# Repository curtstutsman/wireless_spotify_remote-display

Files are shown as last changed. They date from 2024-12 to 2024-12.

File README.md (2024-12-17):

Wireless Spotify Remote Control and Display
Curt Stutsman & Nicholas Watanabe
https://github.com/curtstutsman/wireless_spotify_remote-display

Introduction
	Our group elected to implement a wireless Spotify remote control and album art display utilizing Spotify’s API to control the listening state of the user. Some features of the project include a rotary encoder (which doubled as a push button) and a 64x64 LED matrix. The rotary encoder was purposed for all input, allowing the user to adjust volume with rotations and toggle play/pause and skip to next or previous songs with single, double, and triple taps. The LED matrix was the primary output of the system, displaying in real time the album art of whatever song was currently playing. To achieve wireless communication with Spotify’s api, our group employed and ESP32-WROOM-32E wireless module. The rest of the functionality (LED driving, GPIO interface, etc.) was implemented on an STM32F103.

Figure 1: System Block Diagram

Hardware Overview
	Our project did not require an extensive list of hardware components to achieve the desired functionality. For the LED matrix, we used a 64x64 panel purchased from adafruit with a 2.5mm pitch. Each LED held a one bit value for each of red, green, and blue channels. The matrix as a whole was controlled via the HUB75 protocol, a standard for these types of LED matrices that utilized 16 different signals in the case of our matrix. The 16 signals of the HUB75 protocol were connected and controlled from the GPIO pins of the STM32. The rotary encoder was also controlled via GPIO pins on the MCU. We used a simple UART connection between the STM32 and the ESP32 to send commands to the ESP and to receive image data into the STM. A few other trivial components were included in the final PCB design such as reset buttons, headers for programming, and decoupling capacitors. The full schematic and PCB layout is given below and is linked on our github repository.

Figure 2: Schematic

Figure 3: PCB Layout

Software Overview
	Because we utilized two different chips in our project, the software was split between the STM32F103, which handled LED driving and input control, and the ESP32, which handled communication with the Spotify API and JPEG Decoding. All code can be found in the main.c file of the STM32 source code and the esp32_sketch.ino file of the ESP32 source code, both available on the github repo.

	The first functionality implemented was the button control. The rotary encoder consists of three signals, two for rotation encoding and one for the button. All three channels were connected to GPIO pins and configured to interrupt the CPU at the rising edge of the signal. Pushes to the button increase the tap count variable. The main loop would then check if tap count was greater than zero and enough time had passed since the last tap (to account for double and triple taps) and then send the corresponding command over UART to the ESP32. Interrupts for rotation of the encoder worked in a similar fashion, except a comparison had to be done between the two rotation signals to determine if the rotation was clockwise or counter clockwise so we could tell whether to send the increase or decrease volume command. The LED driving code is by far the most complicated of all the software we wrote. The first task was understanding and implementing the HUB75 protocol, which involved the control of 6 different color signals, 5 addressing signals, and 3 control signals all operating in unison to even turn on the display. Another challenge stemmed from the fact that each LED actually only held one bit for red, green, and blue each, meaning if we wanted to display a color that wasn’t a direct combination of these three, we had to implement a PWM control over the LEDs. For example, to display a red color with 50% intensity, we would have to turn on the red color for that pixel for 50% of the cycles. We were able to adequately control this by looping through the range of the bit magnitude of our colors and adjusting the delay the pixel was on for by this magnitude, giving the appearance of different colors. This however, required extremely fast speeds in order to avoid flickering in the display. The actual pixel data was received directly from ESP32 into an image buffer, which was used to draw from.

	In comparison the code for the ESP32 was simpler apart from a few small details. All of the ESP32 development was done in the Arduino IDE, which made programming the chip much easier. Many of the functions were simple HTTP requests based on their respective commands from the rotary encoder input. The ESP32 was constantly listening for these commands over the serial line it shared with the STM32. The ESP was also constantly checking if the album link had changed, meaning a new song was playing and new image data needed to be sent to the STM32. If there was a new song, it was downloaded from the link (which is provided by the Spotify API), saved to SPIFFS (the ESP32’s built in filesystem), decoded into the raw pixel values, formatted to fit our 8 bits of color standard (RGB332) and sent over UART to the STM32 for storage in its image buffer. There are a few authorization requirements as well as set up steps in the Spotify Developer Dashboard to grant permissions to our project to view and control a selected spotify account, but these are not included in our source code and can be deduced from Spotify’s Web API Documentation. 

Design Challenges and Solutions:
An initial challenge we ran into was the wifi module. To begin we first used the ESP8266 which had less capabilities (and was much harder to use than the ESP32). We were originally trying to rely on the AT command set from Espressif to control the chip, however both the ESP8266 and the AT Firmware were unable to connect to the WPA2-Enterprise level security deployed by the IllinoisNet wifi network. Also, employing only AT commands would not give us enough control over the wireless chip. As a solution, we switched to the more powerful ESP32 and the Arduino IDE, which allowed us to upload code straight to the chip as well as utilize some helpful WiFi libraries.

Another large issue we faced was the refresh rate of the LED matrix. Matrices controlled by the HUB75 protocol only actually turn on two rows of LEDs at a time, and only while the Output Enable signal is high. The rows are cycled on and on so fast that to the human eye it appears to be a fully lit screen. However, if the driver is not updating the rows fast enough, major flickering will occur on the screen. Furthermore, implementing PWM and more than 3 bits of color meant even more cycles until an entire image was properly displayed (and more memory to store the image buffer). To overcome this, we elected to use a larger and faster MCU than the standard STM32L0 given to us. We also spent a lot of time optimizing our main display loop, trying to avoid calculations within the loop wherever possible and instead relying on lookup-tables defined on startup for proper calculations. We also had to bypass the HAL interface for writing to the GPIO pins, and instead wrote directly to the GPIO registers on the chip. 

 When we implemented the PCB board we ran into the issue uploading code. The new STM we used for the PCB (STM32F103) needs to have the reset pin connected to the programmer when uploading code. To solve this we soldered a wire to both pins on the PCB. Furthermore, we had to create two different voltage sources as our rotary encoder required 5V to operate while the rest of the components like the microcontroller and wifi module required 3.3V.

Project Replication

If one wishes to replicate this project in its entirety, the steps taken are as follows:

1. Download the gbr files from github repo, and send them to your favorite pcb manufacturer (you may want to make the wiring changes mentioned in the third paragraph of section IV).
2. Purchase the parts listed in FinalPCBBoard1/FinalPCBBoard1.xml in the repo
3. Solder all of the components to the board
4. Program the ESP32 using the Arduino IDE and the provided sketch + libraries
5. Create a new STM32 project selecting the F103 as the part and add all of the files from the github repo (be sure the pinouts are the same as the final.ioc file)
6. Program the STM32 and ESP32 on your PCB
7. Supply 3.3V directly to the LDO output pins
8. Apply a 5V souce to the power source on the rotary encoder

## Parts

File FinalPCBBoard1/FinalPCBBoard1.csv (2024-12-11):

Source: | C:\Users\ntw5\Documents\FinalPCBBoard1\FinalPCBBoard1.kicad_sch
Date: | 11/19/2024 4:20:24 PM
Tool: | Eeschema (6.0.5)
Generator: | C:\Program Files\KiCad\6.0\bin\scripting\plugins/bom_csv_grouped_by_value.py
Component Count: | 27
Individual Components:
Item | Qty | Reference(s) | Value | LibPart | Footprint | Datasheet
 |  | C1 | 1u | Device:C | Capacitor_SMD:C_0805_2012Metric_Pad1.18x1.45mm_HandSolder | ~
 |  | C4 | 1u | Device:C | Capacitor_SMD:C_0805_2012Metric_Pad1.18x1.45mm_HandSolder | ~
 |  | C7 | 1u | Device:C | Capacitor_SMD:C_0805_2012Metric_Pad1.18x1.45mm_HandSolder | ~
 |  | C10 | 1u | Device:C | Capacitor_SMD:C_0805_2012Metric_Pad1.18x1.45mm_HandSolder | ~
 |  | C11 | 1u | Device:C | Capacitor_SMD:C_0805_2012Metric_Pad1.18x1.45mm_HandSolder | ~
 |  | C12 | 1u | Device:C | Capacitor_SMD:C_0805_2012Metric_Pad1.18x1.45mm_HandSolder | ~
 |  | C13 | 1u | Device:C | Capacitor_SMD:C_0805_2012Metric_Pad1.18x1.45mm_HandSolder | ~
 |  | C14 | 1u | Device:C | Capacitor_SMD:C_0805_2012Metric_Pad1.18x1.45mm_HandSolder | ~
 |  | C15 | 1u | Device:C | Capacitor_SMD:C_0805_2012Metric_Pad1.18x1.45mm_HandSolder | ~
 |  | ESPBOOT1 | SW_Push | Switch:SW_Push | Button_Switch_THT:SW_PUSH_6mm_H4.3mm | ~
 |  | ESPEN1 | SW_Push | Switch:SW_Push | Button_Switch_THT:SW_PUSH_6mm_H4.3mm | ~
 |  | ESPPROGRAM1 | Conn_01x06 | Connector_Generic:Conn_01x06 | Connector_PinSocket_2.54mm:PinSocket_1x06_P2.54mm_Horizontal | ~
 |  | FB1 | FerriteBead | Device:FerriteBead | Ferrite_THT:LairdTech_28C0236-0JW-10 | ~
 |  | J1 | USB_C_Receptacle_USB2.0 | Connector:USB_C_Receptacle_USB2.0 | Connector_USB:USB_C_Receptacle_GCT_USB4085 | https://www.usb.org/sites/default/files/documents/usb_type-c.zip
 |  | J2 | Conn_02x08_Odd_Even | Connector_Generic:Conn_02x08_Odd_Even | Connector_PinHeader_2.54mm:PinHeader_2x08_P2.54mm_Vertical | ~
 |  | J3 | Conn_01x05 | Connector_Generic:Conn_01x05 | Connector_PinSocket_2.54mm:PinSocket_1x05_P2.54mm_Horizontal | ~
 |  | J4 | Conn_02x10_Odd_Even | Connector_Generic:Conn_02x10_Odd_Even | Connector_PinSocket_2.54mm:PinSocket_2x10_P2.54mm_Vertical | ~
 |  | R1 | 10k | Device:R | Resistor_SMD:R_0805_2012Metric_Pad1.20x1.40mm_HandSolder | ~
 |  | R2 | 10k | Device:R | Resistor_SMD:R_0805_2012Metric_Pad1.20x1.40mm_HandSolder | ~
 |  | R3 | 10k | Device:R | Resistor_SMD:R_0805_2012Metric_Pad1.20x1.40mm_HandSolder | ~
 |  | R4 | 10k | Device:R | Resistor_SMD:R_0805_2012Metric_Pad1.20x1.40mm_HandSolder | ~
 |  | STMPROGRAM1 | Conn_01x06 | Connector_Generic:Conn_01x06 | Connector_PinSocket_2.54mm:PinSocket_1x06_P2.54mm_Vertical | ~
 |  | STMRST1 | SW_Push | Switch:SW_Push | Button_Switch_THT:SW_PUSH_6mm_H4.3mm | ~
 |  | STMRST2 | SW_Push | Switch:SW_Push | Button_Switch_THT:SW_PUSH_6mm_H4.3mm | ~
 |  | U1 | ESP32-WROOM-32 | RF_Module:ESP32-WROOM-32 | RF_Module:ESP32-WROOM-32 | https://www.espressif.com/sites/default/files/documentation/esp32-wroom-32_datasheet_en.pdf
 |  | U2 | TC1262-33 | Regulator_Linear:TC1262-33 | Package_TO_SOT_SMD:SOT-223 | http://ww1.microchip.com/downloads/en/DeviceDoc/21373C.pdf
 |  | U3 | STM32F103C8T6 | MCU_ST_STM32F1:STM32F103C8Tx | Package_QFP:LQFP-48_7x7mm_P0.5mm | http://www.st.com/st-web-ui/static/active/en/resource/technical/document/datasheet/CD00161566.pdf
Collated Components:
Item | Qty | Reference(s) | Value | LibPart | Footprint | Datasheet
1 | 9 | C1, C4, C7, C10, C11, C12, C13, C14, C15 | 1u | Device:C | Capacitor_SMD:C_0805_2012Metric_Pad1.18x1.45mm_HandSolder | ~
2 | 4 | ESPBOOT1, ESPEN1, STMRST1, STMRST2 | SW_Push | Switch:SW_Push | Button_Switch_THT:SW_PUSH_6mm_H4.3mm | ~
3 | 1 | ESPPROGRAM1 | Conn_01x06 | Connector_Generic:Conn_01x06 | Connector_PinSocket_2.54mm:PinSocket_1x06_P2.54mm_Horizontal | ~
4 | 1 | FB1 | FerriteBead | Device:FerriteBead | Ferrite_THT:LairdTech_28C0236-0JW-10 | ~
5 | 1 | J1 | USB_C_Receptacle_USB2.0 | Connector:USB_C_Receptacle_USB2.0 | Connector_USB:USB_C_Receptacle_GCT_USB4085 | https://www.usb.org/sites/default/files/documents/usb_type-c.zip
6 | 1 | J2 | Conn_02x08_Odd_Even | Connector_Generic:Conn_02x08_Odd_Even | Connector_PinHeader_2.54mm:PinHeader_2x08_P2.54mm_Vertical | ~
7 | 1 | J3 | Conn_01x05 | Connector_Generic:Conn_01x05 | Connector_PinSocket_2.54mm:PinSocket_1x05_P2.54mm_Horizontal | ~
8 | 1 | J4 | Conn_02x10_Odd_Even | Connector_Generic:Conn_02x10_Odd_Even | Connector_PinSocket_2.54mm:PinSocket_2x10_P2.54mm_Vertical | ~
9 | 4 | R1, R2, R3, R4 | 10k | Device:R | Resistor_SMD:R_0805_2012Metric_Pad1.20x1.40mm_HandSolder | ~
10 | 1 | STMPROGRAM1 | Conn_01x06 | Connector_Generic:Conn_01x06 | Connector_PinSocket_2.54mm:PinSocket_1x06_P2.54mm_Vertical | ~
11 | 1 | U1 | ESP32-WROOM-32 | RF_Module:ESP32-WROOM-32 | RF_Module:ESP32-WROOM-32 | https://www.espressif.com/sites/default/files/documentation/esp32-wroom-32_datasheet_en.pdf
12 | 1 | U2 | TC1262-33 | Regulator_Linear:TC1262-33 | Package_TO_SOT_SMD:SOT-223 | http://ww1.microchip.com/downloads/en/DeviceDoc/21373C.pdf
13 | 1 | U3 | STM32F103C8T6 | MCU_ST_STM32F1:STM32F103C8Tx | Package_QFP:LQFP-48_7x7mm_P0.5mm | http://www.st.com/st-web-ui/static/active/en/resource/technical/document/datasheet/CD00161566.pdf

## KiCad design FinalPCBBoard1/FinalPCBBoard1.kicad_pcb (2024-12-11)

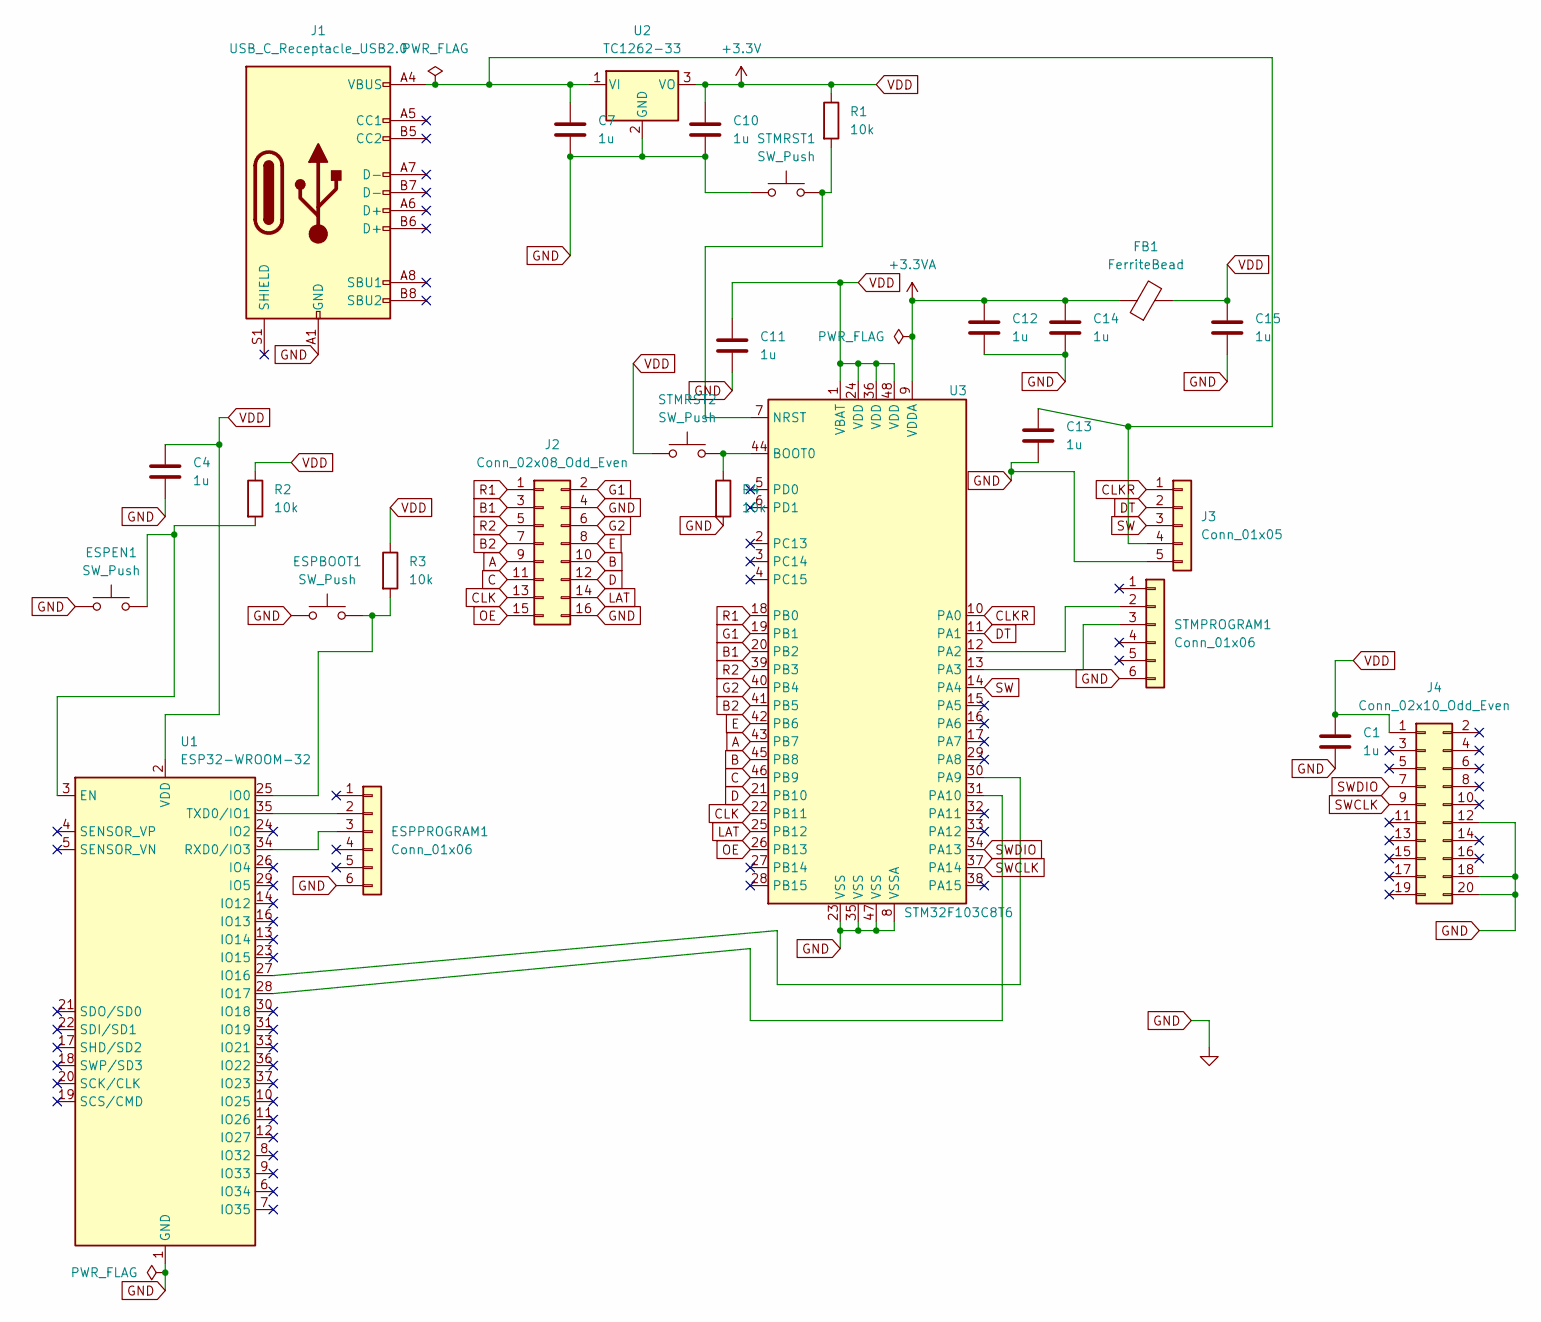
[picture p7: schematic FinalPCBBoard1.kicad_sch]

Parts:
C1, C4, C7, C10, C11, C12, C13, C14, C15: 1u; C_0805_2012Metric_Pad1.18x1.45mm_HandSolder
ESPBOOT1: SW_Push; SW_PUSH_6mm_H4.3mm
ESPEN1: SW_Push; SW_PUSH_6mm_H4.3mm
ESPPROGRAM1: Conn_01x06; PinSocket_1x06_P2.54mm_Horizontal
FB1: FerriteBead; LairdTech_28C0236-0JW-10
J1: USB_C_Receptacle_USB2.0; USB_C_Receptacle_GCT_USB4085
J2: Conn_02x08_Odd_Even; PinHeader_2x08_P2.54mm_Vertical
J3: Conn_01x05; PinSocket_1x05_P2.54mm_Horizontal
J4: Conn_02x10_Odd_Even; PinSocket_2x10_P2.54mm_Vertical
R1, R2, R3, R4: 10k; R_0805_2012Metric_Pad1.20x1.40mm_HandSolder
STMPROGRAM1: Conn_01x06; PinSocket_1x06_P2.54mm_Vertical
STMRST1, STMRST2: SW_Push; SW_PUSH_6mm_H4.3mm
U1: ESP32-WROOM-32
U2: TC1262-33; SOT-223
U3: STM32F103C8T6; LQFP-48_7x7mm_P0.5mm

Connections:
+3.3VA: C12.1, C14.1, FB1.1, U3.9 (VDDA)
A: J2.9, U3.43 (PB7)
B: J2.10, U3.45 (PB8)
B1: J2.3, U3.20 (PB2)
B2: J2.7, U3.41 (PB5)
C: J2.11, U3.46 (PB9)
CLK: J2.13, U3.22 (PB11)
CLKR: J3.1, U3.10 (PA0)
D: J2.12, U3.21 (PB10)
DT: J3.2, U3.11 (PA1)
E: J2.8, U3.42 (PB6)
G1: J2.2, U3.19 (PB1)
G2: J2.6, U3.40 (PB4)
GND: C1.2, C4.2, C7.2, C10.2, C11.2, C12.2, C13.2, C14.2, C15.2, ESPBOOT1.1, ESPEN1.1, ESPPROGRAM1.6, J1.A1 (GND), J1.A12 (GND), J1.B1 (GND), J1.B12 (GND), J2.4, J2.16, J3.5, J4.12, J4.18, J4.20, R4.2, STMPROGRAM1.6, STMRST1.1, U1.1 (GND), U1.15 (GND), U1.38 (GND), U1.39 (GND), U2.2 (GND), U3.8 (VSSA), U3.23 (VSS), U3.35 (VSS), U3.47 (VSS)
LAT: J2.14, U3.25 (PB12)
unnamed: C7.1, C13.1, J1.A4 (VBUS), J1.A9 (VBUS), J1.B4 (VBUS), J1.B9 (VBUS), J3.4, U2.1 (VI)
unnamed: ESPBOOT1.2, R3.2, U1.25 (IO0)
unnamed: ESPEN1.2, R2.2, U1.3 (EN)
unnamed: ESPPROGRAM1.2, U1.35 (TXD0/IO1)
unnamed: ESPPROGRAM1.3, U1.34 (RXD0/IO3)
unnamed: R1.2, STMRST1.2, U3.7 (NRST)
unnamed: STMPROGRAM1.2, U3.12 (PA2)
unnamed: STMPROGRAM1.3, U3.13 (PA3)
unnamed: U1.27 (IO16), U3.30 (PA9)
unnamed: U1.28 (IO17), U3.31 (PA10)
unnamed: R4.1, STMRST2.2, U3.44 (BOOT0)
OE: J2.15, U3.26 (PB13)
R1: J2.1, U3.18 (PB0)
R2: J2.5, U3.39 (PB3)
SW: J3.3, U3.14 (PA4)
SWCLK: J4.9, U3.37 (PA14)
SWDIO: J4.7, U3.34 (PA13)
VDD: C1.1, C4.1, C10.1, C11.1, C15.1, FB1.2, J4.1, R1.1, R2.1, R3.1, STMRST2.1, U1.2 (VDD), U2.3 (VO), U3.1 (VBAT), U3.24 (VDD), U3.36 (VDD), U3.48 (VDD)

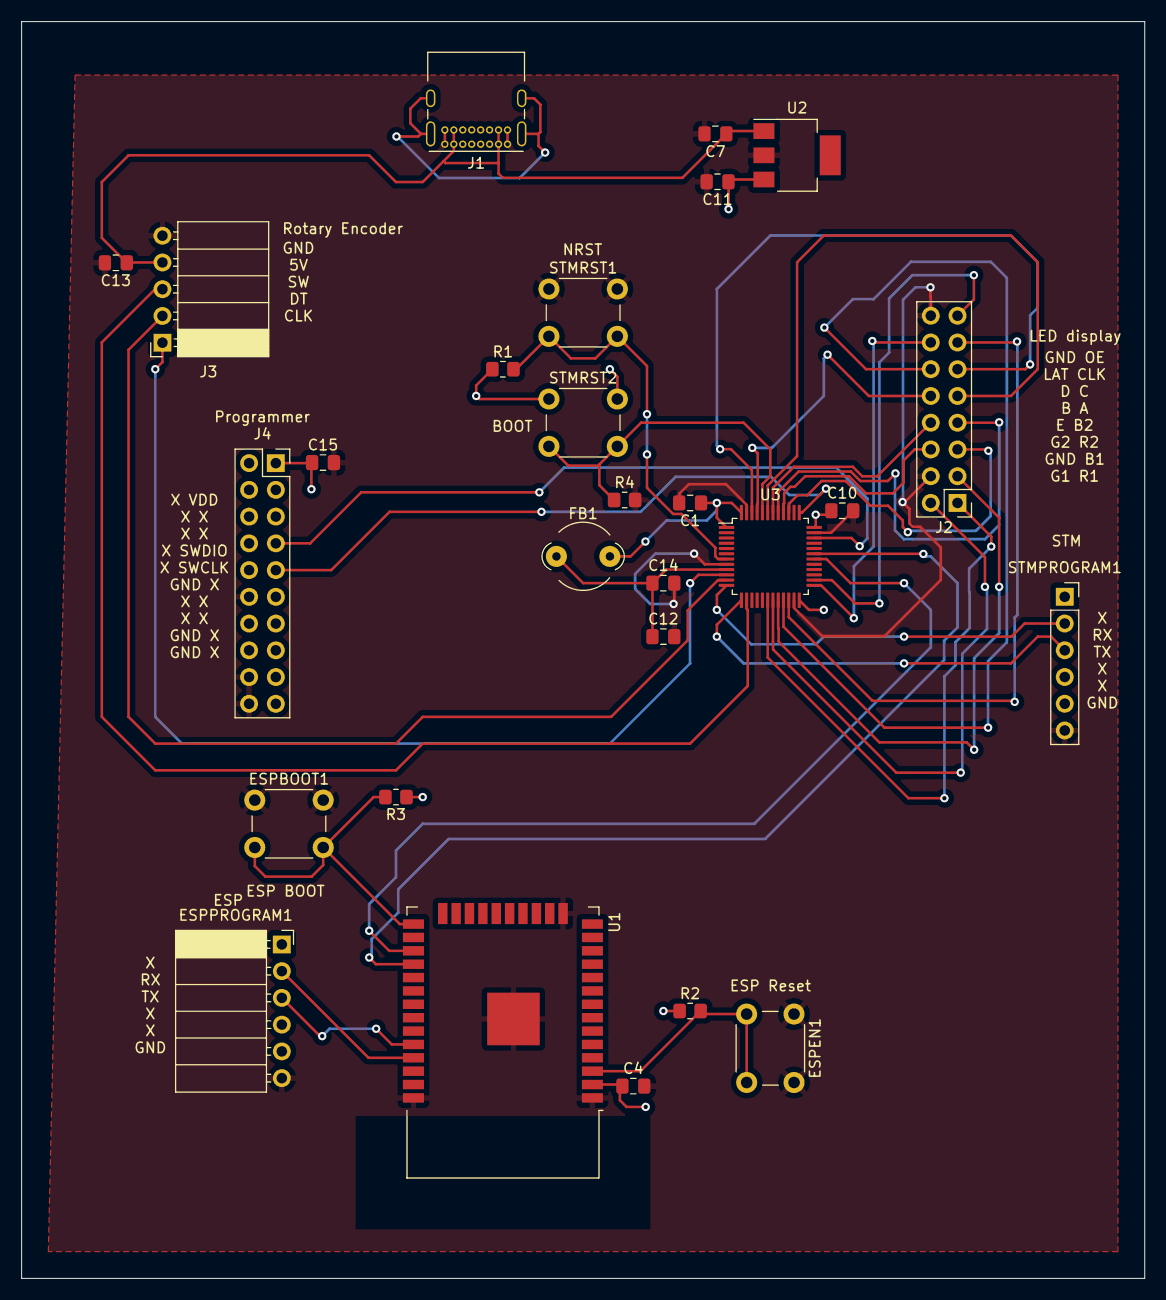
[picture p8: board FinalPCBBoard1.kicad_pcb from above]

Board: 2 copper layers, 106.7 x 119.4 mm, 27 parts (0 on the bottom side), 33 nets.

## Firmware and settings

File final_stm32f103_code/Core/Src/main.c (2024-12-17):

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
/* Includes ------------------------------------------------------------------*/
#include "main.h"

/* USER CODE BEGIN PTD */
#define IMAGE_SIZE 64
#define IMAGE_DATA_SIZE 4096
#define MAX_PWM_BITS 3
/* USER CODE END PTD */

UART_HandleTypeDef huart1;
UART_HandleTypeDef huart2;

/* USER CODE BEGIN PV */
uint32_t lastButtonPressTime = 0;
uint32_t lastRotationTime = 0;
uint8_t tapCount = 0;
const uint32_t debounceDelay = 100;
const uint32_t tapTimeout = 500;
int8_t encoderDirection = 0;
uint8_t lastStateA = 0;
const char* command = "";
uint8_t imageBuffer[IMAGE_SIZE][IMAGE_SIZE];
uint32_t rowAddressValues[32];
uint32_t bsrrLookupTable[64];
uint8_t pixelLookupTable[MAX_PWM_BITS][256];  // 3 PWM bits x 256 pixel values
const int pwmBitsRed = 3;
const int pwmBitsGreen = 3;
const int pwmBitsBlue = 2;
const int maxPwmBits = 3; // Maximum number of bits among R, G, B
int baseDelay = 200;
/* USER CODE END PV */

void SystemClock_Config(void);
static void MX_GPIO_Init(void);
static void MX_USART2_UART_Init(void);
static void MX_USART1_UART_Init(void);
/* USER CODE BEGIN PFP */
void handleButtonAction(void);
void togglePlayPause(void);
void skipToNextSong(void);
void skipToPrevSong(void);
void adjustVolume(void);
void updateDisplay(void);
void init_buf(void);
void initRowAddressValues(void);
void initBsrrLookupTable(void);
/* USER CODE END PFP */

/* USER CODE BEGIN 0 */

// Interrupt handler for both rotation and button press
void HAL_GPIO_EXTI_Callback(uint16_t GPIO_Pin)
{
    uint32_t currentTime = HAL_GetTick();

    if (GPIO_Pin == GPIO_PIN_0)  // Pins A of the encoder
    {

    	//Debounce Rotation
    	if ((currentTime - lastRotationTime) > debounceDelay)
    	{
			// Read the state of both encoder pins
			uint8_t stateA = HAL_GPIO_ReadPin(GPIOA, GPIO_PIN_0);  // Encoder pin A
			uint8_t stateB = HAL_GPIO_ReadPin(GPIOA, GPIO_PIN_1);  // Encoder pin B

			// Determine rotation direction
			if (stateA != lastStateA){
				if (stateA != stateB) {
					encoderDirection = 1;  // Clockwise (CW)
				} else {
					encoderDirection = -1;  // Counterclockwise (CCW)
				}

				// Adjust the volume based on the rotation
				adjustVolume();
				encoderDirection = 0;
				lastRotationTime = currentTime;
			}
			lastStateA = stateA;
    	}

    }

    // Handle button press (connected to GPIO_PIN_4)
    if (GPIO_Pin == GPIO_PIN_4)  // Button press on the encoder
    {
		// Debounce the button press
		if ((currentTime - lastButtonPressTime) > debounceDelay)
		{
			// Register the button press and start counting taps
			tapCount++;

			// Update last button press time
			lastButtonPressTime = currentTime;
		}
   }
}

//UART Interrupt handler for receiving image data
void HAL_UART_RxCpltCallback(UART_HandleTypeDef *huart)
{
    if (huart->Instance == USART1)
    {
        // Restart UART reception
        HAL_UART_Receive_IT(&huart1, (uint8_t*)imageBuffer, IMAGE_DATA_SIZE);
    }
}


// Function to determine what action to perform based on tap count
void handleButtonAction(void)
{
	if (tapCount == 1){
		togglePlayPause();
	}
	else if (tapCount == 2){
		skipToNextSong();
	}
	else if (tapCount == 3){
		skipToPrevSong();
	}
	else{
	}
}

// Volume adjustment based on rotary encoder direction
void adjustVolume(void)
{
    if (encoderDirection > 0)
    {
        // Clockwise rotation: Increase volume
    	command = "raiseVolume\n";
    }
    else if (encoderDirection < 0)
    {
        // Counterclockwise rotation: Decrease volume
        command = "lowerVolume\n";
    }
    else{
    	return;
    }
	// Send 'command' to ESP32 via UART (hlpuart1)
	HAL_UART_Transmit(&huart1, (uint8_t*)command, strlen(command), HAL_MAX_DELAY);
}

// Action for single tap (play/pause)
void togglePlayPause(void)
{
    // Code to send play/pause command to Spotify
	command = "togglePlay\n";
	// Send 'command' to ESP32 via UART (hlpuart1)
	HAL_UART_Transmit(&huart1, (uint8_t*)command, strlen(command), HAL_MAX_DELAY);
}

// Action for double tap (next song)
void skipToNextSong(void)
{
    // Code to send next song command to Spotify
	command = "nextSong\n";
	// Send 'command' to ESP32 via UART (hlpuart1)
	(HAL_UART_Transmit(&huart1, (uint8_t*)command, strlen(command), HAL_MAX_DELAY) != HAL_OK);
}

// Action for triple tap (previous song)
void skipToPrevSong(void)
{
    // Code to send previous song command to Spotify
	command = "previousSong\n";
	// Send 'command' to ESP32 via UART (hlpuart1)
	(HAL_UART_Transmit(&huart1, (uint8_t*)command, strlen(command), HAL_MAX_DELAY) != HAL_OK);
}

// Function to set a pixel at (x, y) with RGB332 data
void setPixel(int x, int y, uint8_t r, uint8_t g, uint8_t b) {
    // Ensure coordinates are within bounds
    if (x < 0 || x >= IMAGE_SIZE || y < 0 || y >= IMAGE_SIZE) return;

    // Limit color components to their respective bit sizes
    r &= 0x07; // 3 bits for Red
    g &= 0x07; // 3 bits for Green
    b &= 0x03; // 2 bits for Blue

    // Combine RGB components into a single byte
    uint8_t pixelData = r | (g << 3) | (b << 6);

    // Store the pixel data
    imageBuffer[y][x] = pixelData;
}


void init_buf(){
    for (int y = 0; y < 32; y++) {
        for (int x = 0; x < IMAGE_SIZE; x++) {
            setPixel(x, y, 0x00, 0x07, 0x00); // Green 
        }
    }
    for (int y = 32; y < IMAGE_SIZE; y++) {
        for (int x = 0; x < IMAGE_SIZE; x++) {
            setPixel(x, y, 0x00, 0x00, 0x00); // Black 
        }
    }
}


void initRowAddressValues(void) {
    for (int row = 0; row < 32; row++) {
        uint32_t value = 0;

        // A line (PB7)
        if (row & 0x01) value |= (1 << 7);    // Set A
        else            value |= (1 << (7+16)); // Reset A

        // B line (PB8)
        if (row & 0x02) value |= (1 << 8);
        else            value |= (1 << (8+16));

        // C line (PB9)
        if (row & 0x04) value |= (1 << 9);
        else            value |= (1 << (9+16));

        // D line (PB10)
        if (row & 0x08) value |= (1 << 10);
        else            value |= (1 << (10+16));

        // E line (PB6)
        if (row & 0x10) value |= (1 << 6);
        else            value |= (1 << (6+16));

        rowAddressValues[row] = value;
    }
}


void initBsrrLookupTable(void) {
    for (int i = 0; i < 64; i++) {
        uint32_t bsrrValue = 0;

        int r1 = (i >> 0) & 1;
        int g1 = (i >> 1) & 1;
        int b1 = (i >> 2) & 1;
        int r2 = (i >> 3) & 1;
        int g2 = (i >> 4) & 1;
        int b2 = (i >> 5) & 1;

        // R1 = PB0
        bsrrValue |= r1 ? (1 << 0) : (1 << (0+16));
        // G1 = PB1
        bsrrValue |= g1 ? (1 << 1) : (1 << (1+16));
        // B1 = PB2
        bsrrValue |= b1 ? (1 << 2) : (1 << (2+16));
        // R2 = PB3
        bsrrValue |= r2 ? (1 << 3) : (1 << (3+16));
        // G2 = PB4
        bsrrValue |= g2 ? (1 << 4) : (1 << (4+16));
        // B2 = PB5
        bsrrValue |= b2 ? (1 << 5) : (1 << (5+16));

        bsrrLookupTable[i] = bsrrValue;
    }
}

void initPixelLookupTable() {
    for (int pwmBit = 0; pwmBit < MAX_PWM_BITS; pwmBit++) {
        uint8_t bitMaskRed = 1 << (2 - pwmBit);
        uint8_t bitMaskGreen = 1 << (2 - pwmBit);
        uint8_t bitMaskBlue = 1 << (1 - pwmBit);  // Since Blue has only 2 bits

        for (int pixelValue = 0; pixelValue < 256; pixelValue++) {
            uint8_t r = pixelValue & 0x07;         // 3 bits for Red
            uint8_t g = (pixelValue >> 3) & 0x07;  // 3 bits for Green
            uint8_t b = (pixelValue >> 6) & 0x03;  // 2 bits for Blue

            uint8_t r_on = (r & bitMaskRed) ? 1 : 0;
            uint8_t g_on = (g & bitMaskGreen) ? 1 : 0;
            uint8_t b_on = (b & bitMaskBlue) ? 1 : 0;

            uint8_t pixelBits = (r_on << 0) | (g_on << 1) | (b_on << 2);

            pixelLookupTable[pwmBit][pixelValue] = pixelBits;
        }
    }
}

void updateDisplay(void) {
    for (int pwmBit = 0; pwmBit < maxPwmBits; pwmBit++) {
        int delay = baseDelay << (maxPwmBits - 1 - pwmBit);
        uint8_t* lookupTable = pixelLookupTable[pwmBit];

        for (int row = 0; row < 32; row++) {
            // Set Row Address Lines
            GPIOB->BSRR = rowAddressValues[row];

            uint8_t* rowPtr1 = imageBuffer[row];
            uint8_t* rowPtr2 = imageBuffer[row + 32];

            for (int col = 0; col < 64; col++) {
                uint8_t pixel1 = rowPtr1[col];
                uint8_t pixel2 = rowPtr2[col];

                uint8_t pixelBits1 = lookupTable[pixel1];
                uint8_t pixelBits2 = lookupTable[pixel2];

                uint8_t pixelBits = pixelBits1 | (pixelBits2 << 3);

                // Set pixel colors using lookup table
                GPIOB->BSRR = bsrrLookupTable[pixelBits];

                // Toggle Clock (CLK = PB11)
                GPIOB->BSRR = (1 << 11);        // Set CLK high
                GPIOB->BSRR = (1 << (11+16));   // Set CLK low
            }

            // Latch Data (LAT = PB12)
            GPIOB->BSRR = (1 << 12);         // LAT high
            GPIOB->BSRR = (1 << (12+16));    // LAT low

            // Enable Display (OE = PB13 active low)
            GPIOB->BSRR = (1 << (13+16));    // OE low (output enabled)

            // Delay proportional to the bit weight
            for (volatile int i = 0; i < delay; i++) {
                __NOP();
            }

            // Disable Display (OE = PB13)
            GPIOB->BSRR = (1 << 13);         // OE high (output disabled)
        }
    }
}
/* USER CODE END 0 */

/**
  * @brief  The application entry point.
  * @retval int
  */
int main(void)
{
  /* MCU Configuration--------------------------------------------------------*/

  /* Reset of all peripherals, Initializes the Flash interface and the Systick. */
  HAL_Init();

  /* Configure the system clock */
  SystemClock_Config();

  /* Initialize all configured peripherals */
  HAL_Delay(500);
  MX_GPIO_Init();
  MX_USART2_UART_Init();
  MX_USART1_UART_Init();
  /* USER CODE BEGIN 2 */
  HAL_UART_Receive_IT(&huart1, (uint8_t*)imageBuffer, IMAGE_DATA_SIZE);
  init_buf();
  initRowAddressValues();
  initBsrrLookupTable();
  initPixelLookupTable();
  /* USER CODE END 2 */

  /* Infinite loop */
  /* USER CODE BEGIN WHILE */
  while (1)
  {
      updateDisplay();
      // Check if the tap timeout has elapsed after the first tap
      if ((tapCount > 0) && (HAL_GetTick() - lastButtonPressTime) > tapTimeout)
      {
          // Call the function to handle the number of taps detected
          handleButtonAction();

          // Reset tap count for the next sequence
          tapCount = 0;
      }
  }
  /* USER CODE END 3 */
}

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


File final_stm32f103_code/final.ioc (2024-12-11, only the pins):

Mcu.UserName=STM32F103C8Tx
PA0-WKUP.Signal=GPXTI0
PA1.Signal=GPXTI1
PA10.Signal=USART1_RX
PA13.Signal=SYS_JTMS-SWDIO
PA14.Signal=SYS_JTCK-SWCLK
PA2.Signal=USART2_TX
PA3.Signal=USART2_RX
PA4.Signal=GPXTI4
PA9.Signal=USART1_TX
PB0.Signal=GPIO_Output
PB1.Signal=GPIO_Output
PB10.Signal=GPIO_Output
PB11.Signal=GPIO_Output
PB12.Signal=GPIO_Output
PB13.Signal=GPIO_Output
PB2.Signal=GPIO_Output
PB3.Signal=GPIO_Output
PB4.Signal=GPIO_Output
PB5.Signal=GPIO_Output
PB6.Signal=GPIO_Output
PB7.Signal=GPIO_Output
PB8.Signal=GPIO_Output
PB9.Signal=GPIO_Output

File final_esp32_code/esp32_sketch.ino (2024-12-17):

#include <WiFi.h>
#include <HTTPClient.h>
#include <base64.h>
#include <ArduinoJson.h>
#include <JPEGDecoder.h>

#define RX2_PIN 16
#define TX2_PIN 17

#define THRESHOLD 127
#define IMAGE_SIZE 64
uint8_t rgbArray[IMAGE_SIZE][IMAGE_SIZE][3];
const char* filename = "/image.jpg";

const char* ssid = "";
const char* password = "";
String client_id = ""; 
String client_secret = ""; 

String accessToken = "";
const char* refresh_token = ""; // Refresh token for getting new access token

String lastAlbumLink = "";
unsigned long previousMillis = 0;
const long interval = 1500;

struct PlaybackState {
  int volumePercent;
  bool isPlaying;
  bool supportsVolume;
  String albumLink;
};
PlaybackState currentState;


PlaybackState getPlaybackState();
PlaybackState waitForValidPlaybackState();
void togglePlayback();
void raiseVolume();
void lowerVolume();
void nextTrack();
void previousTrack();
String getAccessToken();
bool saveImageToSPIFFS(String imageUrl);
bool decodeImageFromSPIFFS();
void sendImageData();
void initializeRgbArray();

void setup() {
    Serial.begin(115200);
    delay(500);
    Serial2.begin(115200, SERIAL_8N1, RX2_PIN, TX2_PIN);

    WiFi.mode(WIFI_STA);
    delay(1000);  // short delay
    Serial.println(WiFi.macAddress());
    
    // Initialize SPIFFS
    if (!SPIFFS.begin(true)) {
        return;
    }

    //Connect to WiFi
    WiFi.begin(ssid, password);
    while (WiFi.status() != WL_CONNECTED) {
        delay(500);
        Serial.print(".");
    }
    
    Serial.println("\nConnected to Wi-Fi!");
    Serial.print("IP Address: ");
    Serial.println(WiFi.localIP());
    
    // Request Access Token
    while (accessToken == ""){
      accessToken = getAccessToken();
    }

    Serial.println(accessToken);
    
     // **Initial Fetch of Album Art**
    currentState = getPlaybackState();
    if (currentState.volumePercent != -1 && currentState.albumLink != "") {
        lastAlbumLink = currentState.albumLink;
        if (saveImageToSPIFFS(lastAlbumLink)) {
            initializeRgbArray();
            if (decodeImageFromSPIFFS()) {
                sendImageData();
            }
        }
    }
}


String getAccessToken() {
  if (WiFi.status() == WL_CONNECTED) {
    
    HTTPClient http;
    String credentials = client_id + ":" + client_secret;
    String base64Credentials = base64::encode(credentials);

    http.begin("https://accounts.spotify.com/api/token");
    http.addHeader("Content-Type", "application/x-www-form-urlencoded");
    http.addHeader("Authorization", "Basic " + base64Credentials);

    String requestBody = "grant_type=refresh_token&refresh_token=" + String(refresh_token);
    int httpResponseCode = http.POST(requestBody);

    if (httpResponseCode == 200) {
      String response = http.getString();
      Serial.println("Access Token Response: " + response);

      // Parse the access token from the response
      int tokenIndex = response.indexOf("\"access_token\":\"");
      if (tokenIndex != -1) {
        int tokenStart = tokenIndex + strlen("\"access_token\":\"");
        int tokenEnd = response.indexOf("\"", tokenStart);
        String accessToken = response.substring(tokenStart, tokenEnd);
        http.end();
        return accessToken;
      } else {
        Serial.println("Access token not found in response.");
      }
    } else {
      Serial.print("Error on sending POST: ");
      Serial.println(httpResponseCode);
      Serial.println(http.getString());
    }

    http.end(); // Free resources
  } else {
    Serial.println("Wi-Fi Disconnected");
  }

  return "";
}


PlaybackState getPlaybackState() {
  
    PlaybackState state = {-1, false, false, ""}; // Default values
    
    if (WiFi.status() == WL_CONNECTED) {
      
        HTTPClient http;
        http.begin("https://api.spotify.com/v1/me/player");
        http.addHeader("Authorization", String("Bearer ") + accessToken);
        http.setTimeout(interval);
        
        // Make the GET request
        int httpResponseCode = http.GET();
        if (httpResponseCode == 200) {
          
            String payload = http.getString();
            // Parse the JSON response
            DynamicJsonDocument doc(1024);
            DeserializationError error = deserializeJson(doc, payload);
            
            if (!error) {
                state.supportsVolume = doc["device"]["supports_volume"];
                state.volumePercent = doc["device"]["volume_percent"]; // Volume percentage
                state.isPlaying = doc["is_playing"]; // Playing state
                state.albumLink = doc["item"]["album"]["images"][2]["url"].as<String>();
            } 
        } 
        http.end();
    } 
    return state; // Return the playback state
}


PlaybackState waitForValidPlaybackState() {
    PlaybackState state;
    do {
        state = getPlaybackState();
        if (state.volumePercent == -1) {
            lastAlbumLink = "";
            initializeRgbArray();
            sendImageData();
            delay(1500);
        }
    } while (state.volumePercent == -1);
    return state;
}


void togglePlayback() {
    HTTPClient http;
    String url;
    
    if (currentState.isPlaying) {
        url = "https://api.spotify.com/v1/me/player/pause";
        http.begin(url);
    } 
    else {
        url = "https://api.spotify.com/v1/me/player/play";
        http.begin(url);
    }
    
    http.addHeader("Authorization", String("Bearer ") + accessToken);
    http.addHeader("Content-Length", "0");
    int httpResponseCode = http.PUT(""); 
    http.end();
}


void raiseVolume() {
    if (currentState.volumePercent < 100 && currentState.supportsVolume) {
      
        int newVolume = currentState.volumePercent + 5; // Increase volume by 5
        if (newVolume > 100) newVolume = 100; // Cap at 100
        
        HTTPClient http;
        String url = "https://api.spotify.com/v1/me/player/volume?volume_percent=" +
        String(newVolume);
        http.begin(url);
        
        // Add the authorization header
        http.addHeader("Authorization", String("Bearer ") + accessToken);
        http.addHeader("Content-Length", "0");
        // Make the PUT request
        int httpResponseCode = http.PUT(""); // Empty body for volume command
        
        if (httpResponseCode > 0) {
            Serial.print("Volume raised to: ");
            Serial.println(newVolume);
            Serial.print("Response Code: ");
            Serial.println(httpResponseCode); // Print HTTP return code
        } 
        else {
            Serial.print("Error on HTTP request: ");
            Serial.println(httpResponseCode);
        }
        // Close connection
        http.end();
    } 
    else {
        Serial.println("Volume is already at maximum.");
    }
}
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

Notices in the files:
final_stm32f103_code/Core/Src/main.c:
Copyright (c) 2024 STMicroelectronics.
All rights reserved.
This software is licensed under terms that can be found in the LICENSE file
